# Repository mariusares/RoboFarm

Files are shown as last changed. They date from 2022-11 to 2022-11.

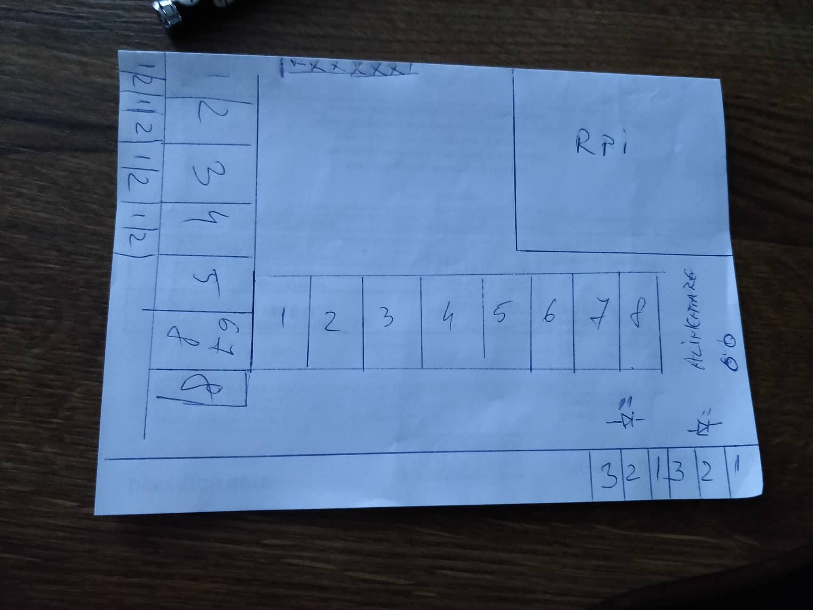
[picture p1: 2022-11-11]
CeresOne/Resources/board 1.jpg

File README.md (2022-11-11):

RoboFarm Greenhouse Automation, Irrigation Automation, and Poultry Farm Automation with Arduino and Raspberry Pi 

Long story short, a few years ago (in 2017 i think), a guy criticized the graphical interface.

At that moment I realized that he has to be a part of the team. 

So the GUI look and feel by Alex Hodorogea 

The PHP GUI (HTML folder) is in the Romanian language. Would be translated at some stage (too busy nowadays).

The sql file contains the MySQL/MariaDB SQL database structure

The default username is admin password admin 

For those who want more than a test, the PCB Layout is available for printing under CeresOne folder.

Initially, I gave up the name RoboFarm, because so many projects with this name. Feel free to name it as you pleased.

Under CeresOne/Resources you can see the pieces of the schematics, and how the power source and PCB board were designed. 

The project can work with a radio module with some software modifications.

Feel free to use it as you pleased. 

First version based on Arduino Mega with Google Docs logs  in production on 2015 :

https://www.youtube.com/watch?v=YMtiKbJgd4w&t=180s

First RaspberryPi + Arduino (Arduino is the sensor hub to feed the RPi data string) + first Web GUI:

https://www.youtube.com/watch?v=SSzuTgg7uxc&t=3s

png folder contains the new (actual) GUI version.

The system is designed to reduce farming costs and effort.

I hope that there would be a very happy farmer. 

The system was designed to help my uncle and every farmer that might need a bit of "help".

RoboFarm can be the best employee, he can ventilate the farm at 5AM if necessary.

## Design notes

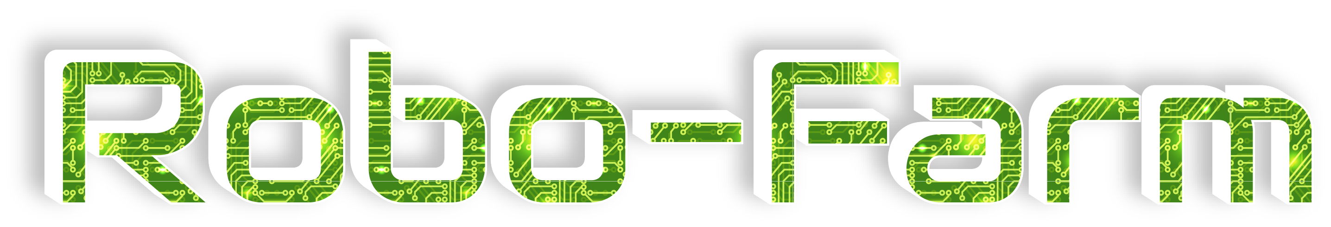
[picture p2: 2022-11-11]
html/img/robo-farm1.png

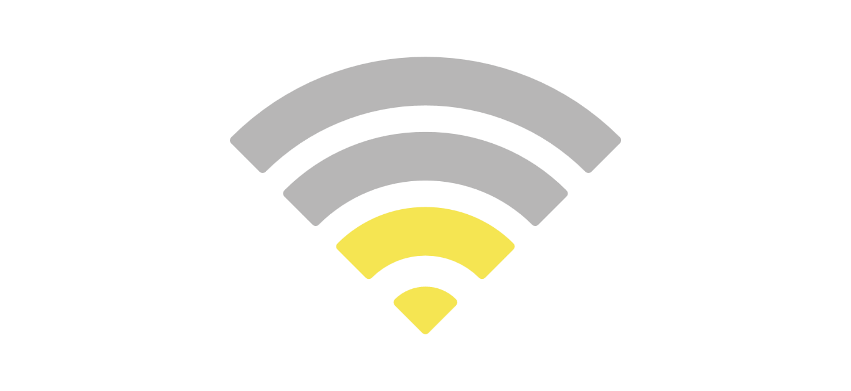
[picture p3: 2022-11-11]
html/img/2wq.png

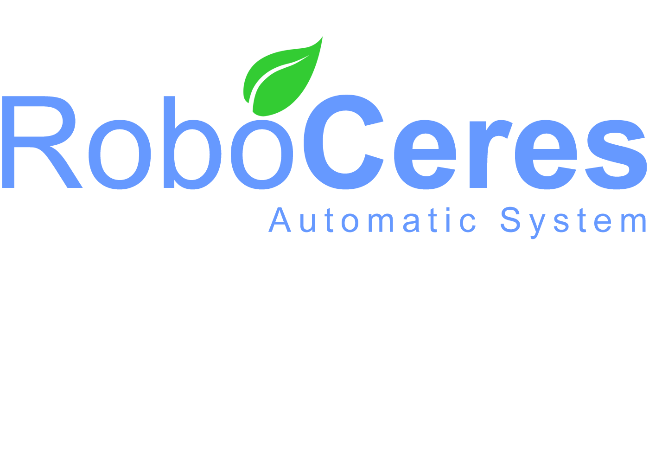
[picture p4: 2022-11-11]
html/img/RoboCeres.png

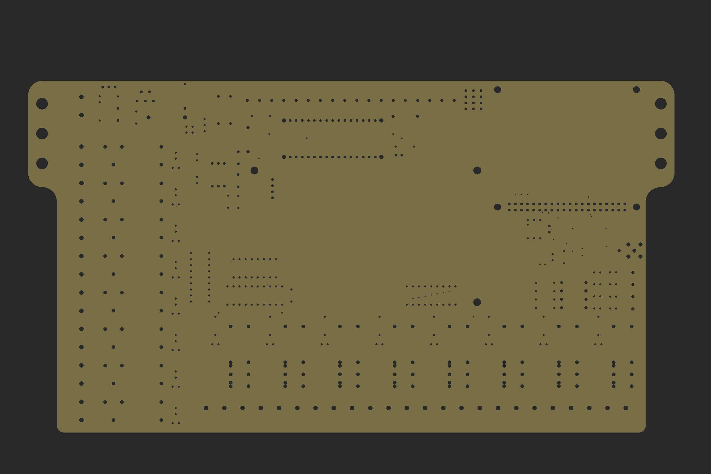
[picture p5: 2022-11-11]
CeresOne/Previews/Drill Map.png

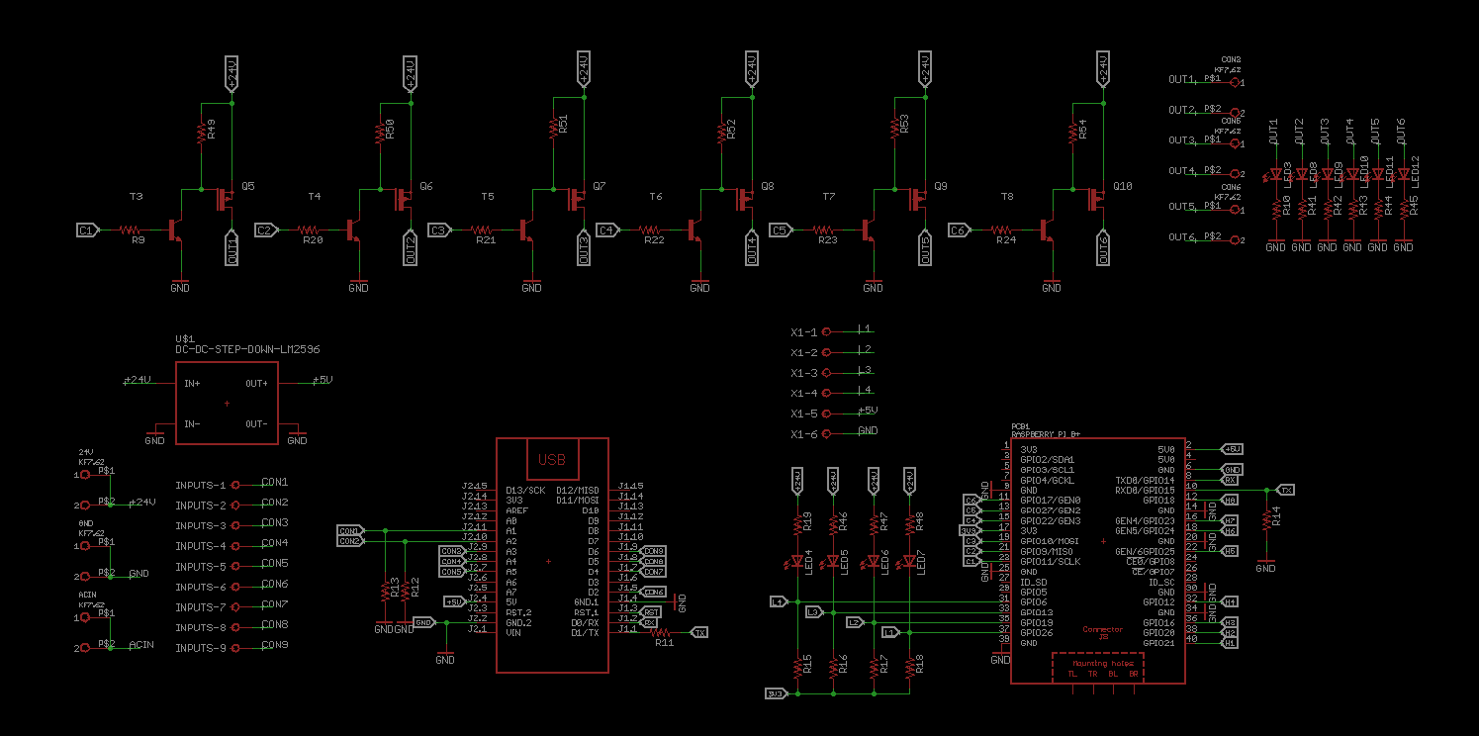
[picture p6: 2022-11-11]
CeresOne/Resources/Capture.PNG

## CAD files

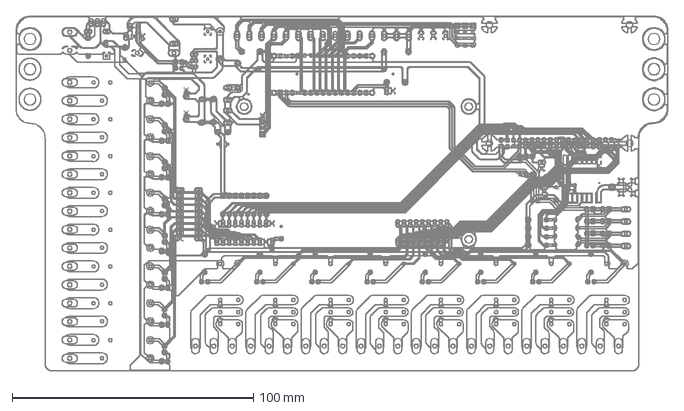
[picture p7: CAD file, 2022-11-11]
CeresOne/CAD/Board Outline.dxf
270.0 x 147.0 mm

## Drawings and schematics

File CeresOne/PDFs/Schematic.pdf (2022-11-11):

VIN J2.1 | GND.2 J2.2 | RST.2 J2.3 | 5V J2.4 | A7 J2.5 | A6 J2.6 | A5 J2.7 | A4 J2.8 | A3 J2.9 | A2 J2.10 | A1 J2.11 | A0 J2.12 | AREF J2.13 | 3V3 J2.14 | D13/SCK J2.15

## USB

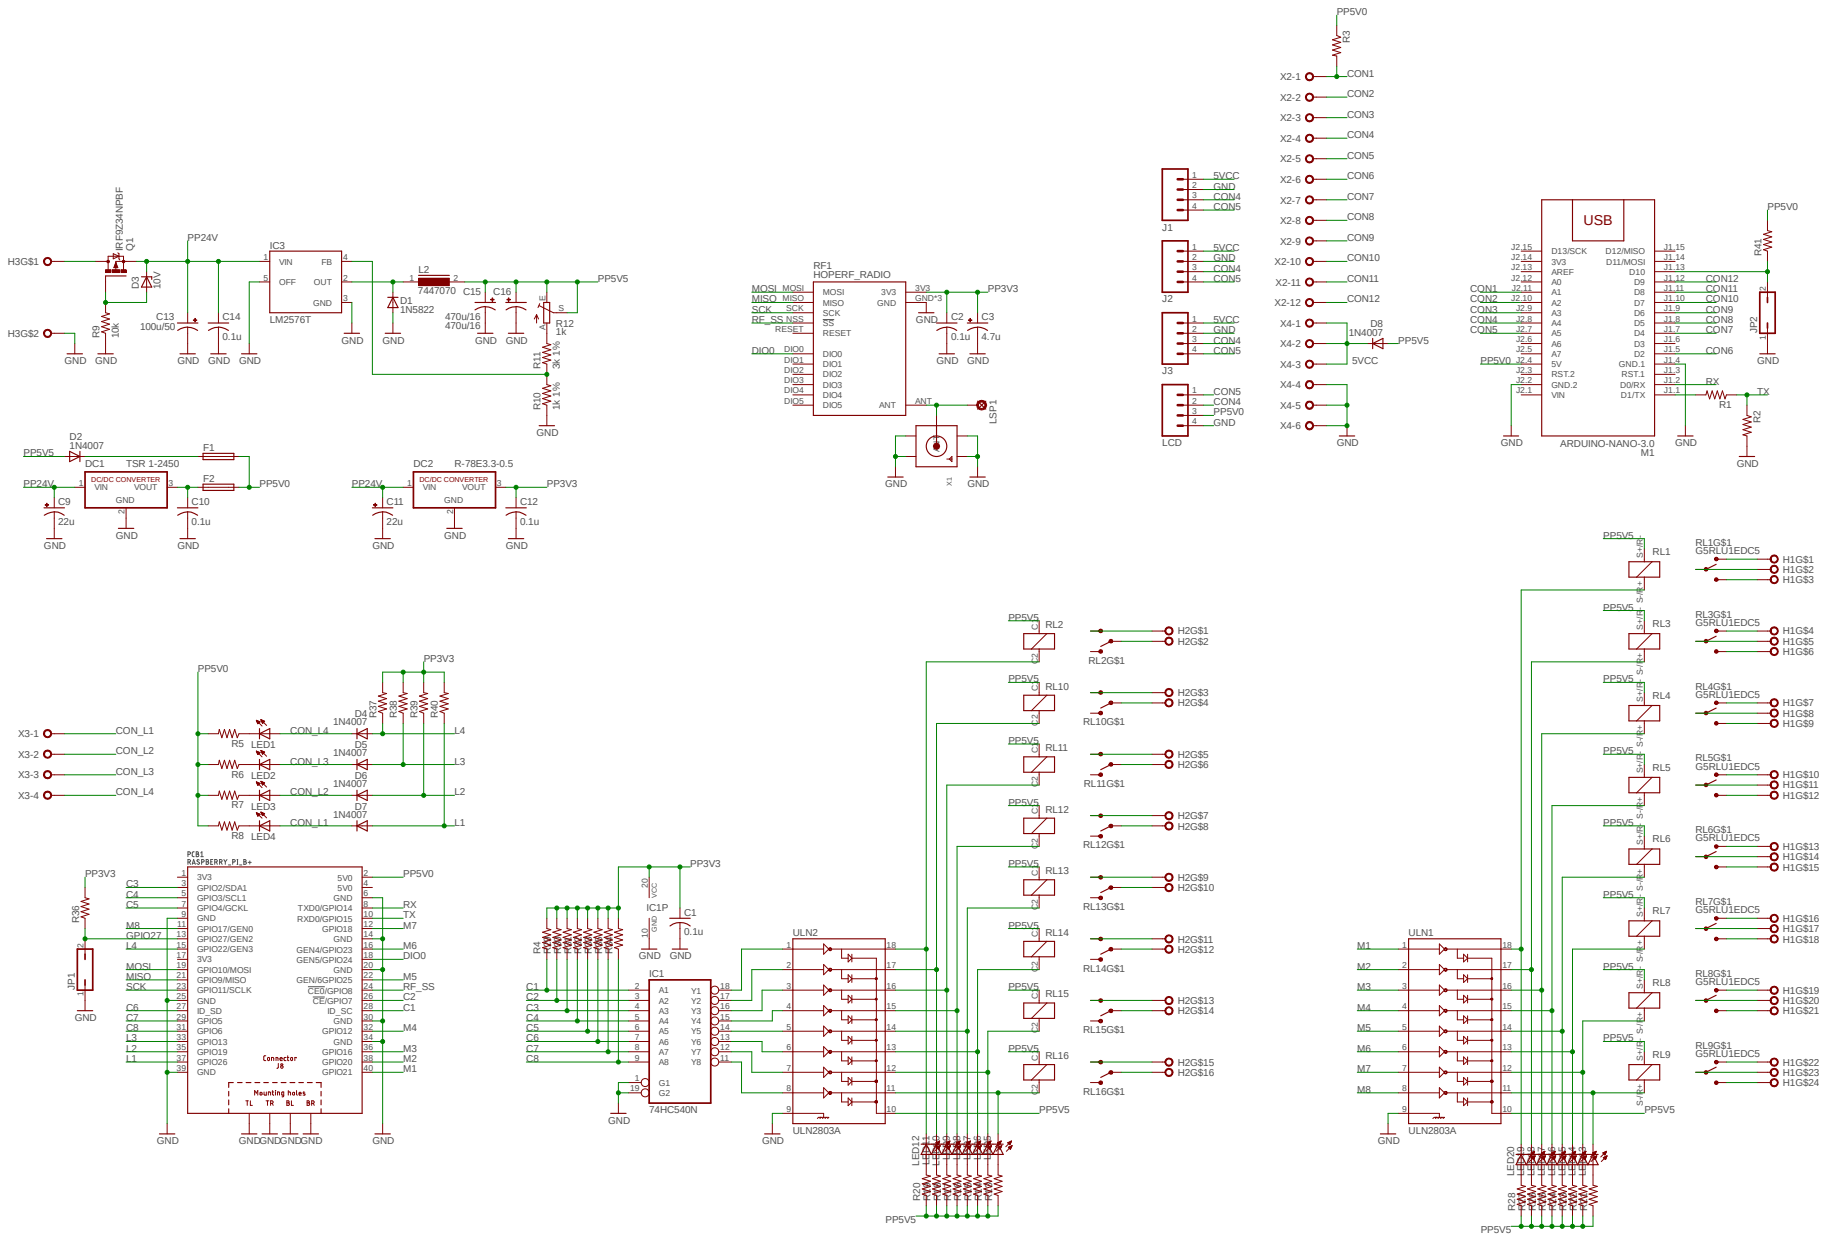
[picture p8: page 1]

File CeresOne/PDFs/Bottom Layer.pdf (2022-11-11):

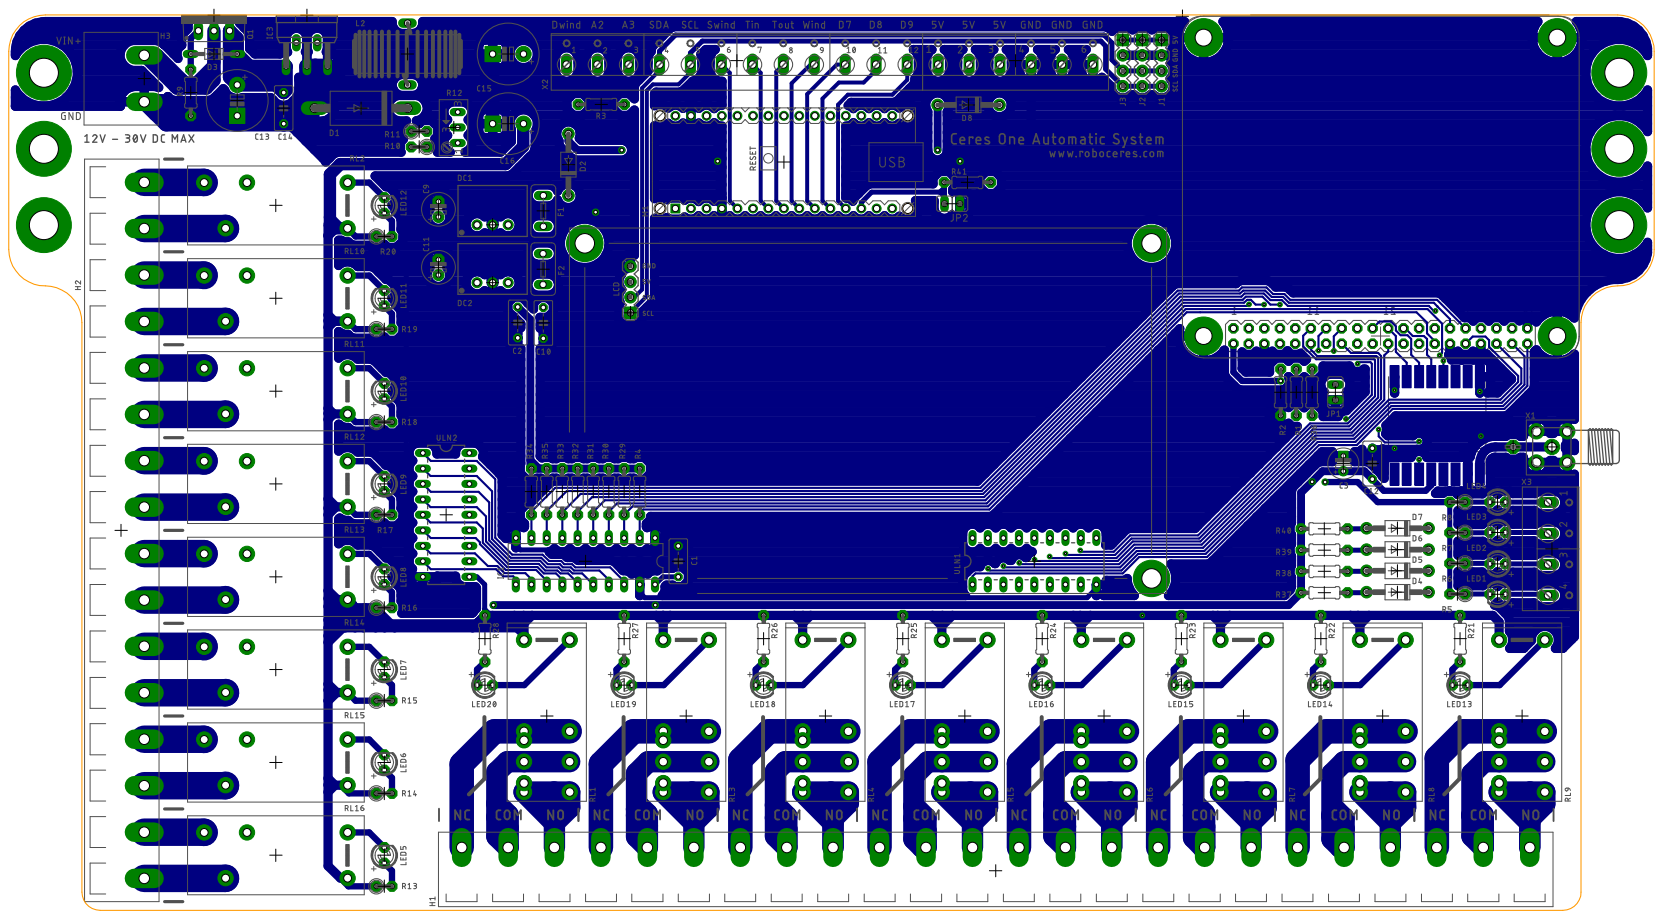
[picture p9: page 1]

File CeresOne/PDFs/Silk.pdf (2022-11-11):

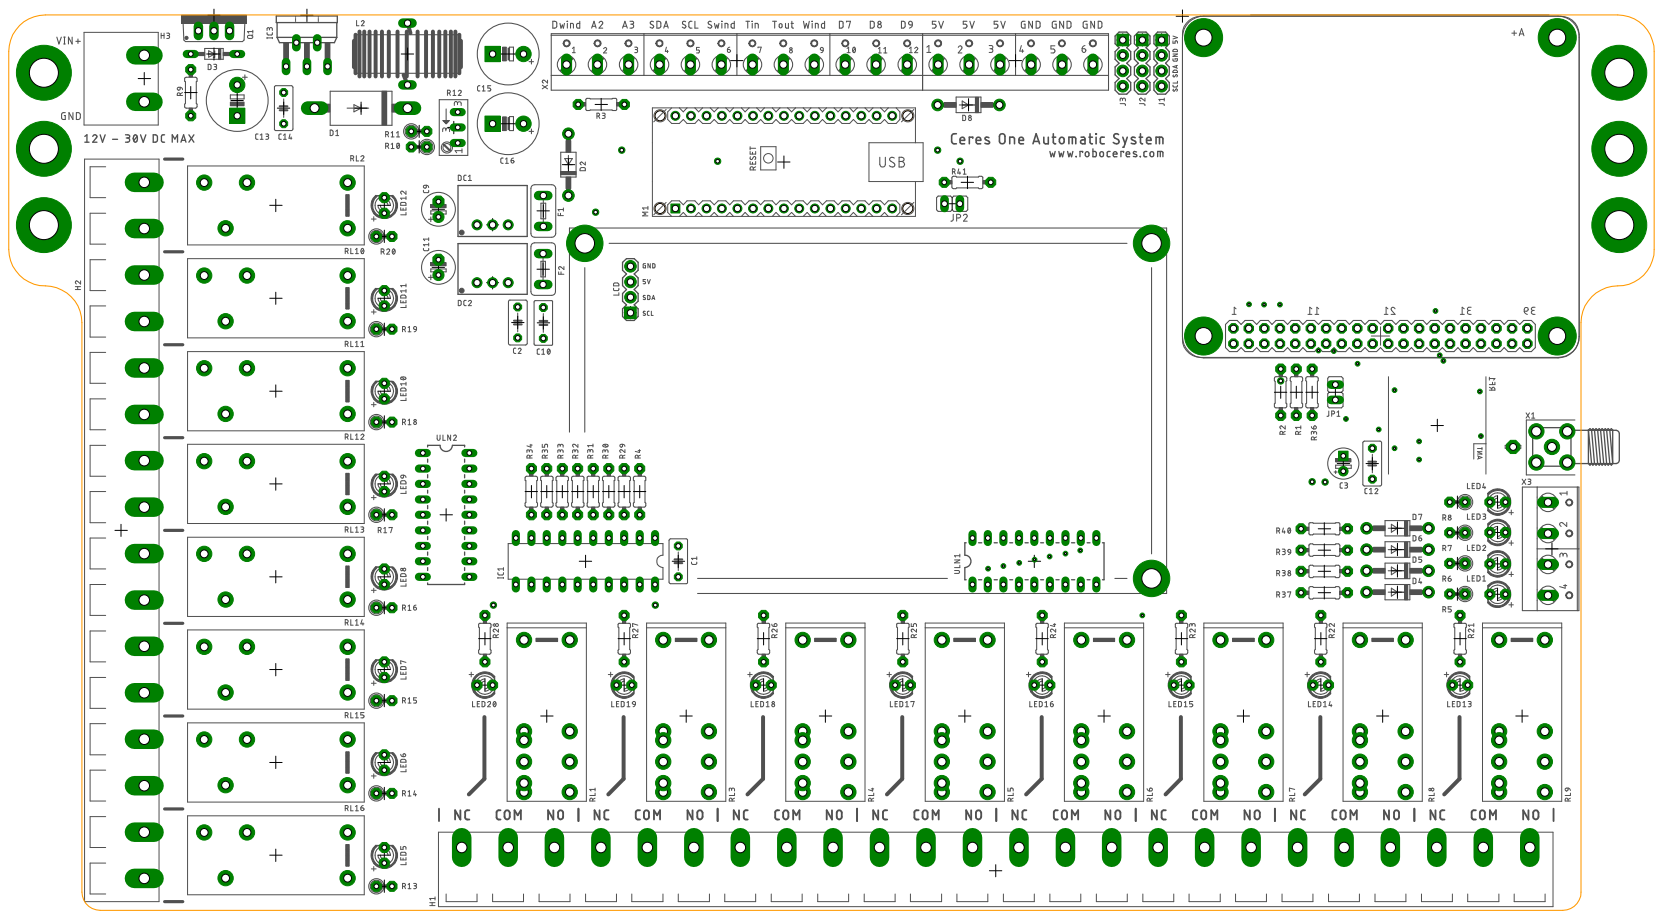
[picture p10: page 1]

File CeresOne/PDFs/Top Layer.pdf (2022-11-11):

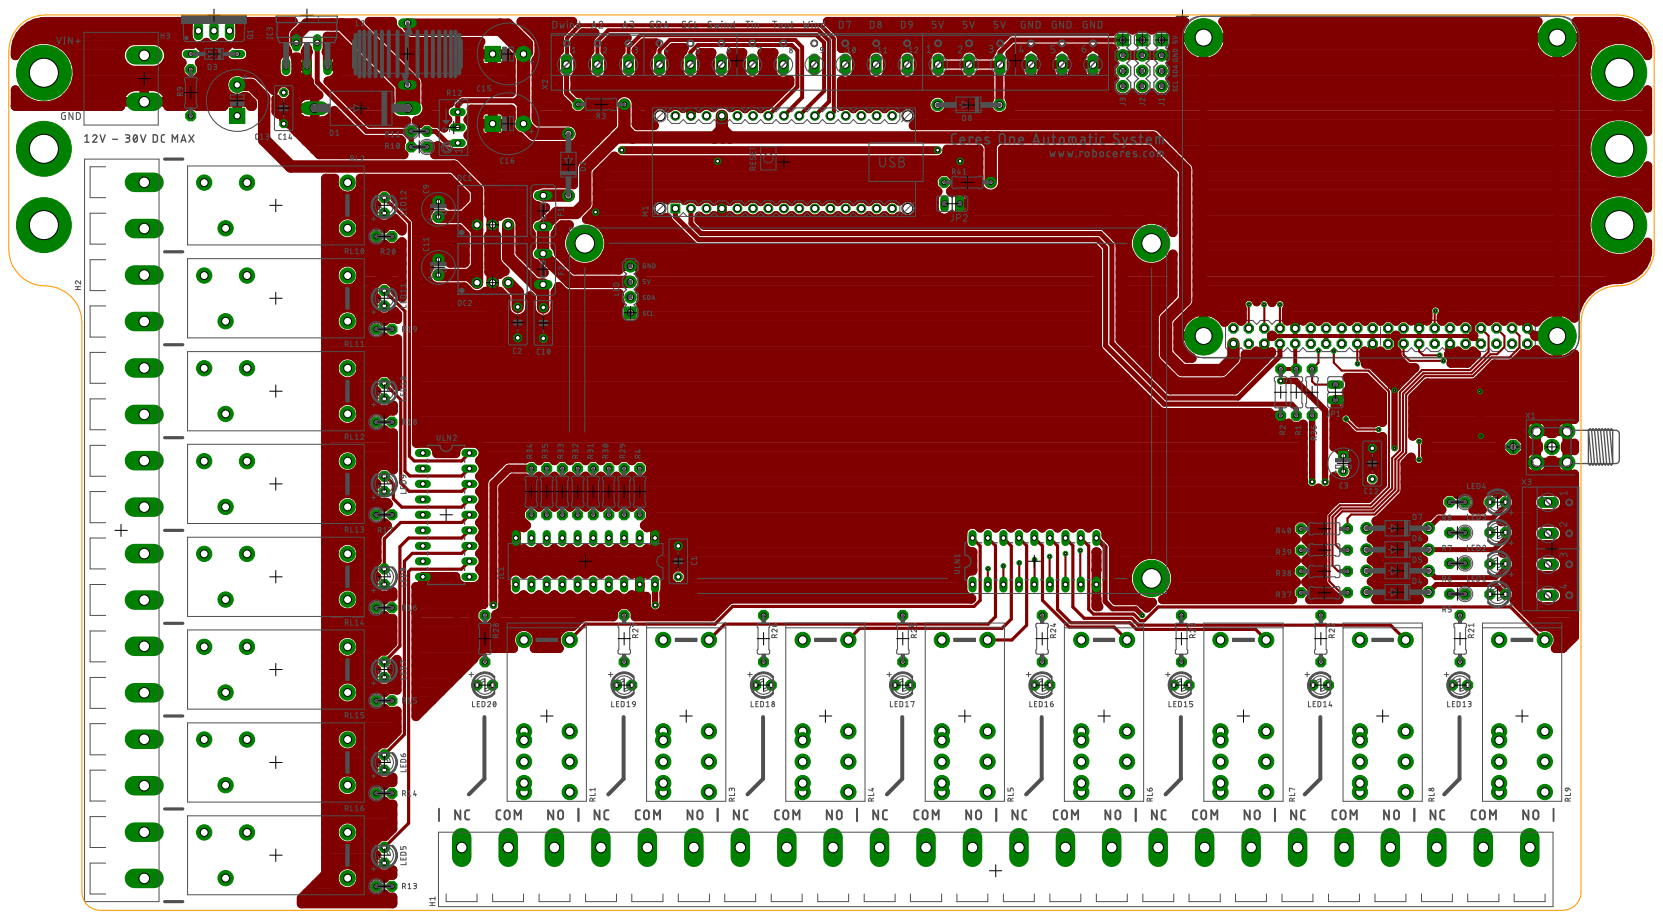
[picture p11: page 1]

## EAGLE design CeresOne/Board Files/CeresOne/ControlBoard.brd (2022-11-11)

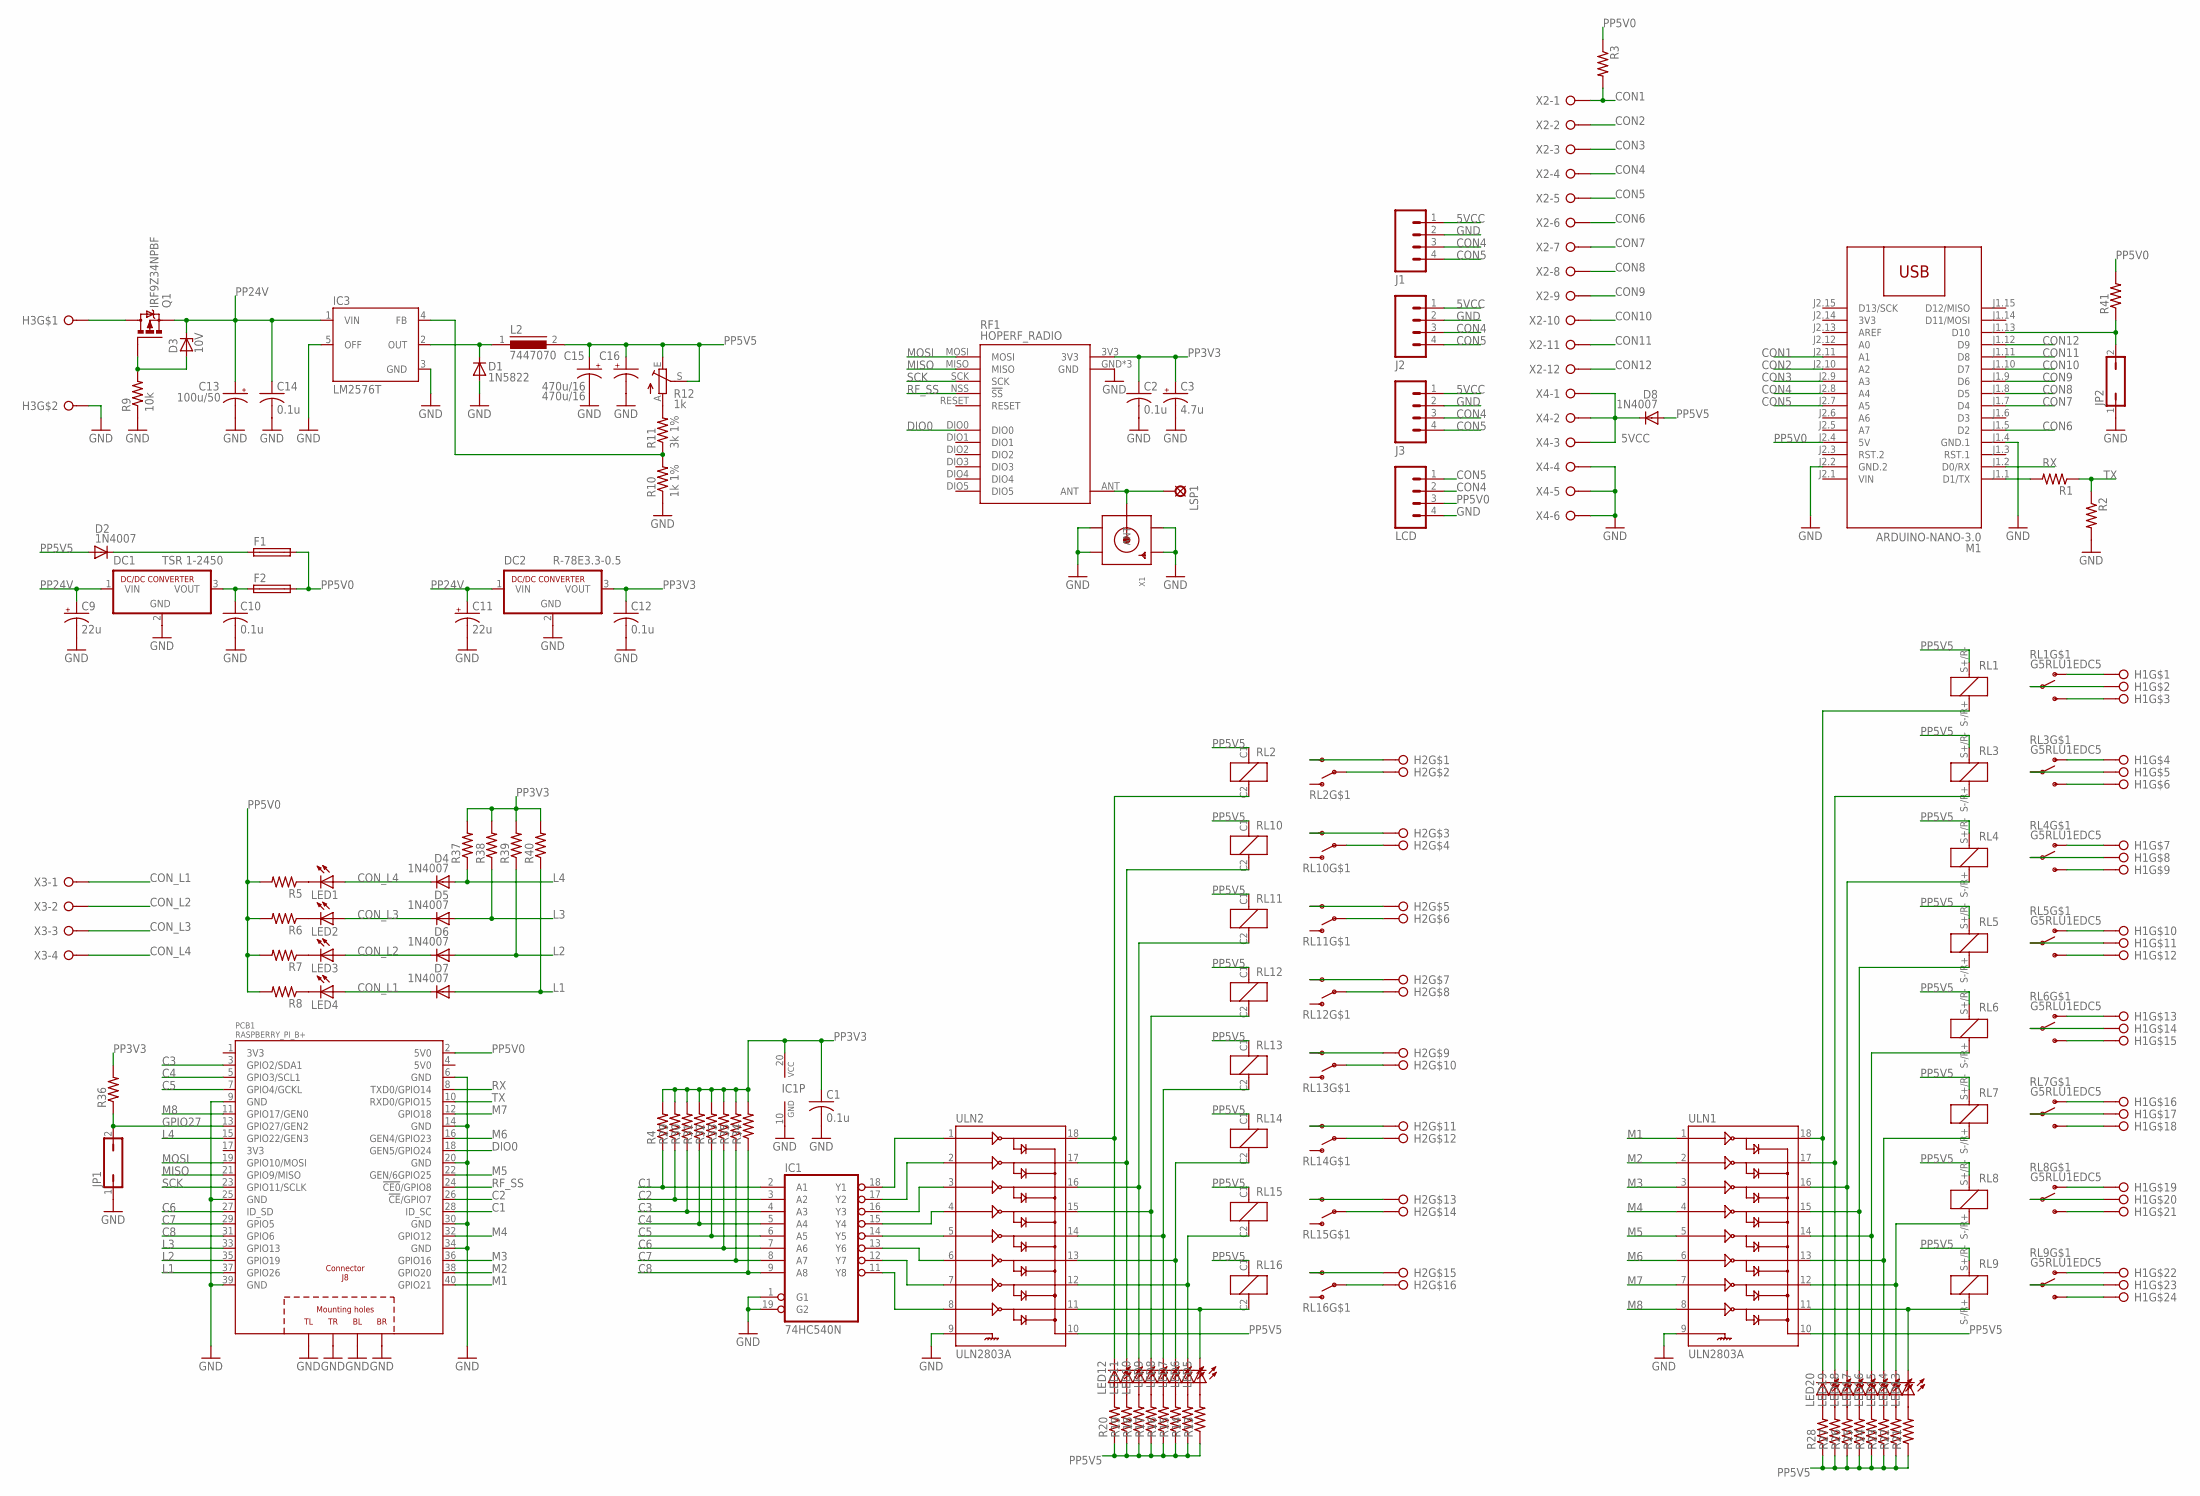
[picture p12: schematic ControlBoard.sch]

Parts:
C1, C2, C10, C12, C14: 0.1u; C050-030X075
C3: 4.7u; E2,5-5
C9, C11: 22u; E2,5-6
C13: 100u/50; E5-10,5
C15, C16: 470u/16; E5-10,5
D1: 1N5822; DO201-15
D2, D4, D5, D6, D7, D8: 1N4007; DO41-10
D3: 10V; DO34Z7
DC1: TSR 1-2450; SIP3
DC2: R-78E3.3-0.5; SIP3
F1, F2: TE5
H1: 24X1(0.300)CONN; 24/7.62CONN
H2: 16X1(0.300)CONN; 16/7.62CONN
H3: 2X1(0.300)CONN; 2/7.62CONN
IC1: 74HC540N; DIL20
IC3: LM2576T; TO220-5
J1, J2, J3: M04PTH; 1X04
JP1, JP2: JP1Q; JP1
L2: 7447070; SFT830D
LCD: M04PTH; 1X04
LED1, LED2, LED3, LED4, LED5, LED6, LED7, LED8, LED9, LED10, LED11, LED12, LED13, LED14, LED15, LED16, LED17, LED18, LED19, LED20: LED3MM
LSP1: LSP11
M1: ARDUINO-NANO-3.0
PCB1: RASPBERRY_PI_B+
Q1: IRF9Z34NPBF; TO220BV
R1, R2, R3, R4, R21, R22, R23, R24, R25, R26, R27, R28, R29, R30, R31, R32, R33, R34, R35, R36, R37, R38, R39, R40, R41: R-US_0204/7; 0204/7
R5, R6, R7, R8, R13, R14, R15, R16, R17, R18, R19, R20: R-US_0207/2V; 0207/2V
R9: 10k; 0204/7
R10: 1k 1%; 0207/2V
R11: 3k 1%; 0207/2V
R12: 1k; RJ9W
RF1: HOPERF_RADIO; RADIO_MODULE
RL1, RL3, RL4, RL5, RL6, RL7, RL8, RL9: G5RLU1EDC5; DOUBLE_RELAY
RL2, RL10, RL11, RL12, RL13, RL14, RL15, RL16: OMIH-SS-105LM,300
ULN1, ULN2: ULN2803A; DIL18
X1: SMACONNECTOR; SMA90_DIP
X2: W237-12P
X3: W237-04P; W237-4P
X4: W237-06P; W237-6P

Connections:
3V3: M1.J2.14 (3V3)
5VCC: D8.C, J1.1, J2.1, J3.1, X4.1, X4.2, X4.3
C1: IC1.2 (A1), PCB1.28 (ID_SC), R4.1
C2: IC1.3 (A2), PCB1.26 (!CE!/GPIO7), R29.1
C3: IC1.4 (A3), PCB1.3 (GPIO2/SDA1), R30.1
C4: IC1.5 (A4), PCB1.5 (GPIO3/SCL1), R31.1
C5: IC1.6 (A5), PCB1.7 (GPIO4/GCKL), R32.1
C6: IC1.7 (A6), PCB1.27 (ID_SD), R33.1
C7: IC1.8 (A7), PCB1.29 (GPIO5), R35.1
C8: IC1.9 (A8), PCB1.31 (GPIO6), R34.1
CON1: M1.J2.11 (A1), R3.2, X2.1
CON2: M1.J2.10 (A2), X2.2
CON3: M1.J2.9 (A3), X2.3
CON4: J1.3, J2.3, J3.3, LCD.2, M1.J2.8 (A4), X2.4
CON5: J1.4, J2.4, J3.4, LCD.1, M1.J2.7 (A5), X2.5
CON6: M1.J1.5 (D2), X2.6
CON7: M1.J1.7 (D4), X2.7
CON8: M1.J1.8 (D5), X2.8
CON9: M1.J1.9 (D6), X2.9
CON10: M1.J1.10 (D7), X2.10
CON11: M1.J1.11 (D8), X2.11
CON12: M1.J1.12 (D9), X2.12
CON_L1: D7.C, LED4.A, X3.1
CON_L2: D6.C, LED3.A, X3.2
CON_L3: D5.C, LED2.A, X3.3
CON_L4: D4.C, LED1.A, X3.4
DIO0: PCB1.18 (GEN5/GPIO24), RF1.DIO0
GND: C1.2, C2.2, C3.-, C9.-, C10.2, C11.-, C12.2, C13.-, C14.2, C15.-, C16.-, D1.A, DC1.2 (GND), DC2.2 (GND), H3.P$2, IC1.1 (G1), IC1.10 (GND), IC1.19 (G2), IC3.3 (GND), IC3.5 (OFF), J1.2, J2.2, J3.2, JP1.1, JP2.1, LCD.4, M1.J1.4 (GND.1), M1.J2.2 (GND.2), PCB1.6 (GND), PCB1.9 (GND), PCB1.14 (GND), PCB1.20 (GND), PCB1.25 (GND), PCB1.30 (GND), PCB1.34 (GND), PCB1.39 (GND), PCB1.PE_BL (BL), PCB1.PE_BR (BR), PCB1.PE_TL (TL), PCB1.PE_TR (TR), R2.2, R9.1, R10.1, RF1.GND, RF1.GND1 (GND), RF1.GND2 (GND), ULN1.9, ULN2.9, X1.GND1, X1.GND2, X1.GND3, X1.GND4, X4.4, X4.5, X4.6
GPIO27: JP1.2, PCB1.13 (GPIO27/GEN2), R36.1
L1: D7.A, PCB1.37 (GPIO26), R40.1
L2: D6.A, PCB1.35 (GPIO19), R39.1
L3: D5.A, PCB1.33 (GPIO13), R38.1
L4: D4.A, PCB1.15 (GPIO22/GEN3), R37.1
M1: PCB1.40 (GPIO21), ULN1.1
M2: PCB1.38 (GPIO20), ULN1.2
M3: PCB1.36 (GPIO16), ULN1.3
M4: PCB1.32 (GPIO12), ULN1.4
M5: PCB1.22 (GEN/6GPIO25), ULN1.5
M6: PCB1.16 (GEN4/GPIO23), ULN1.6
M7: PCB1.12 (GPIO18), ULN1.7
M8: PCB1.11 (GPIO17/GEN0), ULN1.8
MISO: PCB1.21 (GPIO9/MISO), RF1.MISO
MOSI: PCB1.19 (GPIO10/MOSI), RF1.MOSI
unnamed: H1.1, RL1.NC1 (NC), RL1.NC2 (NC), RL1.NC3 (NC)
unnamed: H1.3, RL1.NO1 (NO), RL1.NO2 (NO), RL1.NO3 (NO)
unnamed: H1.4, RL3.NC1 (NC), RL3.NC2 (NC), RL3.NC3 (NC)
unnamed: H1.6, RL3.NO1 (NO), RL3.NO2 (NO), RL3.NO3 (NO)
unnamed: H1.7, RL4.NC1 (NC), RL4.NC2 (NC), RL4.NC3 (NC)
unnamed: H1.9, RL4.NO1 (NO), RL4.NO2 (NO), RL4.NO3 (NO)
unnamed: H1.10, RL5.NC1 (NC), RL5.NC2 (NC), RL5.NC3 (NC)
unnamed: H1.12, RL5.NO1 (NO), RL5.NO2 (NO), RL5.NO3 (NO)
unnamed: H1.13, RL6.NC1 (NC), RL6.NC2 (NC), RL6.NC3 (NC)
unnamed: H1.15, RL6.NO1 (NO), RL6.NO2 (NO), RL6.NO3 (NO)
unnamed: H1.16, RL7.NC1 (NC), RL7.NC2 (NC), RL7.NC3 (NC)
unnamed: H1.18, RL7.NO1 (NO), RL7.NO2 (NO), RL7.NO3 (NO)
unnamed: H1.19, RL8.NC1 (NC), RL8.NC2 (NC), RL8.NC3 (NC)
unnamed: H1.21, RL8.NO1 (NO), RL8.NO2 (NO), RL8.NO3 (NO)
unnamed: H1.22, RL9.NC1 (NC), RL9.NC2 (NC), RL9.NC3 (NC)
unnamed: H1.24, RL9.NO1 (NO), RL9.NO2 (NO), RL9.NO3 (NO)
unnamed: H1.2, RL1.COM1 (COM), RL1.COM2 (COM)
unnamed: H1.5, RL3.COM1 (COM), RL3.COM2 (COM)
unnamed: H1.8, RL4.COM1 (COM), RL4.COM2 (COM)
unnamed: H1.11, RL5.COM1 (COM), RL5.COM2 (COM)
unnamed: H1.14, RL6.COM1 (COM), RL6.COM2 (COM)
unnamed: H1.17, RL7.COM1 (COM), RL7.COM2 (COM)
unnamed: H1.20, RL8.COM1 (COM), RL8.COM2 (COM)
unnamed: H1.23, RL9.COM1 (COM), RL9.COM2 (COM)
unnamed: H2.2, RL2.COM
unnamed: H2.4, RL10.COM
unnamed: H2.6, RL11.COM
unnamed: H2.8, RL12.COM
unnamed: H2.10, RL13.COM
unnamed: H2.12, RL14.COM
unnamed: H2.14, RL15.COM
unnamed: H2.16, RL16.COM
unnamed: H2.1, RL2.NO
unnamed: H2.3, RL10.NO
unnamed: H2.5, RL11.NO
unnamed: H2.7, RL12.NO
unnamed: H2.9, RL13.NO
unnamed: H2.11, RL14.NO
unnamed: H2.13, RL15.NO
unnamed: H2.15, RL16.NO
unnamed: LED13.K (C), RL9.S-/R+ (2), ULN1.11
unnamed: LED14.K (C), RL8.S-/R+ (2), ULN1.12
unnamed: LED15.K (C), RL7.S-/R+ (2), ULN1.13
unnamed: LED16.K (C), RL6.S-/R+ (2), ULN1.14
unnamed: LED17.K (C), RL5.S-/R+ (2), ULN1.15
unnamed: LED18.K (C), RL4.S-/R+ (2), ULN1.16
unnamed: LED19.K (C), RL3.S-/R+ (2), ULN1.17
unnamed: LED20.K (C), RL1.S-/R+ (2), ULN1.18
unnamed: LED12.K (C), RL2.C2 (2), ULN2.18
unnamed: LED11.K (C), RL10.C2 (2), ULN2.17
unnamed: LED10.K (C), RL11.C2 (2), ULN2.16
unnamed: LED9.K (C), RL12.C2 (2), ULN2.15
unnamed: LED8.K (C), RL13.C2 (2), ULN2.14
unnamed: LED7.K (C), RL14.C2 (2), ULN2.13
unnamed: LED6.K (C), RL15.C2 (2), ULN2.12
unnamed: LED5.K (C), RL16.C2 (2), ULN2.11
unnamed: IC1.11 (Y8), ULN2.8
unnamed: IC1.12 (Y7), ULN2.7
unnamed: IC1.13 (Y6), ULN2.6
unnamed: IC1.14 (Y5), ULN2.5
unnamed: IC1.15 (Y4), ULN2.4
unnamed: IC1.16 (Y3), ULN2.3
unnamed: IC1.17 (Y2), ULN2.2
unnamed: IC1.18 (Y1), ULN2.1
unnamed: LSP1.MP, RF1.ANT, X1.ANTENNA (ANT)
unnamed: M1.J1.1 (D1/TX), R1.2
unnamed: LED1.K (C), R5.1
unnamed: LED2.K (C), R6.1
unnamed: LED3.K (C), R7.1
unnamed: D3.A, Q1.G, R9.2
unnamed: IC3.4 (FB), R10.2, R11.1
unnamed: LED4.K (C), R8.1
unnamed: H3.P$1, Q1.D
unnamed: D2.C, F1.1
unnamed: C10.1, DC1.3 (VOUT), F2.1
unnamed: D1.C, IC3.2 (OUT), L2.1
unnamed: R11.2, R12.A
unnamed: LED5.A, R13.2
unnamed: LED6.A, R14.2
unnamed: LED7.A, R15.2
unnamed: LED8.A, R16.2
unnamed: LED9.A, R17.2
unnamed: LED10.A, R18.2
unnamed: LED11.A, R19.2
unnamed: LED12.A, R20.2
unnamed: LED13.A, R21.2
unnamed: LED14.A, R22.2
unnamed: LED15.A, R23.2
unnamed: LED16.A, R24.2
unnamed: LED17.A, R25.2
unnamed: LED18.A, R26.2
unnamed: LED19.A, R27.2
unnamed: LED20.A, R28.2
unnamed: JP2.2, M1.J1.13 (D10), R41.1
PP3V3: C1.1, C2.1, C3.+, C12.1, DC2.3 (VOUT), IC1.20 (VCC), R4.2, R29.2, R30.2, R31.2, R32.2, R33.2, R34.2, R35.2, R36.2, R37.2, R38.2, R39.2, R40.2, RF1.3V3
PP5V0: F1.2, F2.2, LCD.3, M1.J2.4 (5V), PCB1.2 (5V0), R3.1, R5.2, R6.2, R7.2, R8.2, R41.2
PP5V5: C15.+, C16.+, D2.A, D8.A, L2.2, R12.E, R12.S, R13.1, R14.1, R15.1, R16.1, R17.1, R18.1, R19.1, R20.1, R21.1, R22.1, R23.1, R24.1, R25.1, R26.1, R27.1, R28.1, RL1.S+/R- (1), RL2.C1 (1), RL3.S+/R- (1), RL4.S+/R- (1), RL5.S+/R- (1), RL6.S+/R- (1), RL7.S+/R- (1), RL8.S+/R- (1), RL9.S+/R- (1), RL10.C1 (1), RL11.C1 (1), RL12.C1 (1), RL13.C1 (1), RL14.C1 (1), RL15.C1 (1), RL16.C1 (1), ULN1.10, ULN2.10
PP24V: C9.+, C11.+, C13.+, C14.1, D3.C, DC1.1 (VIN), DC2.1 (VIN), IC3.1 (VIN), Q1.S
RF_SS: PCB1.24 (!CE0!/GPIO8), RF1.NSS (!SS)
RX: M1.J1.2 (D0/RX), PCB1.8 (TXD0/GPIO14)
SCK: PCB1.23 (GPIO11/SCLK), RF1.SCK
TX: PCB1.10 (RXD0/GPIO15), R1.1, R2.1
VIN: M1.J2.1 (VIN)

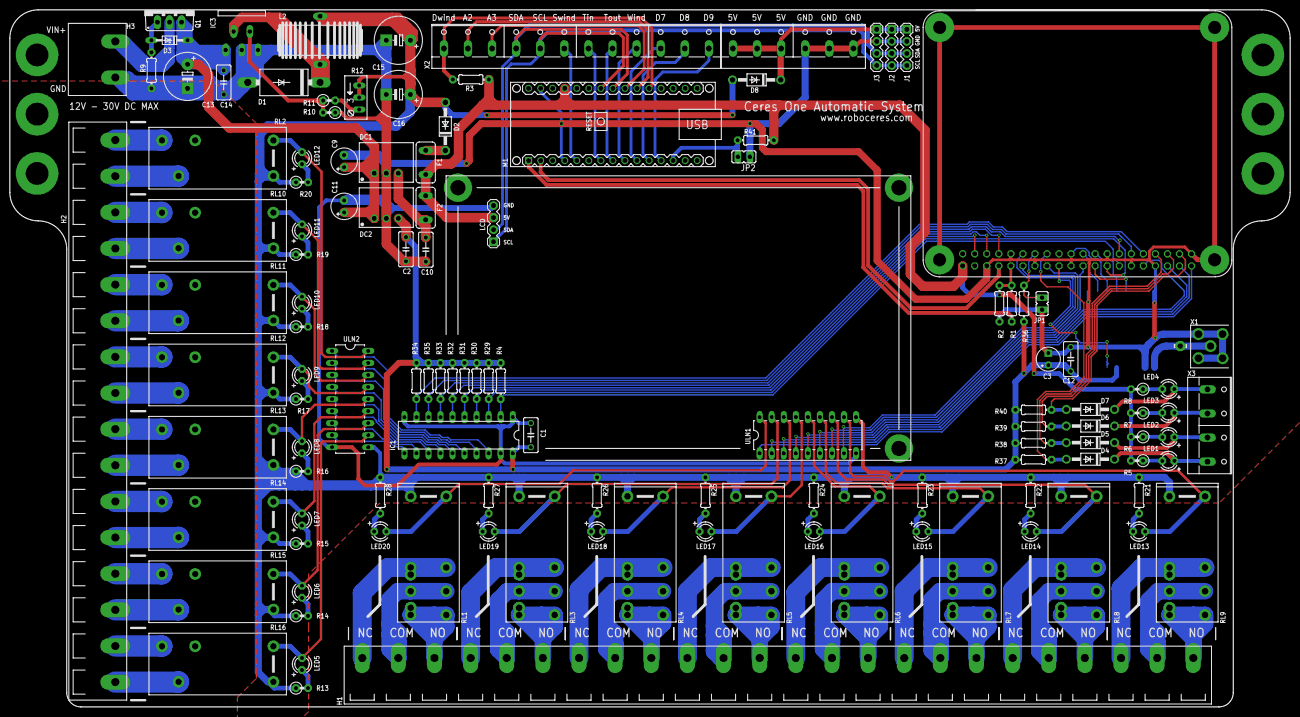
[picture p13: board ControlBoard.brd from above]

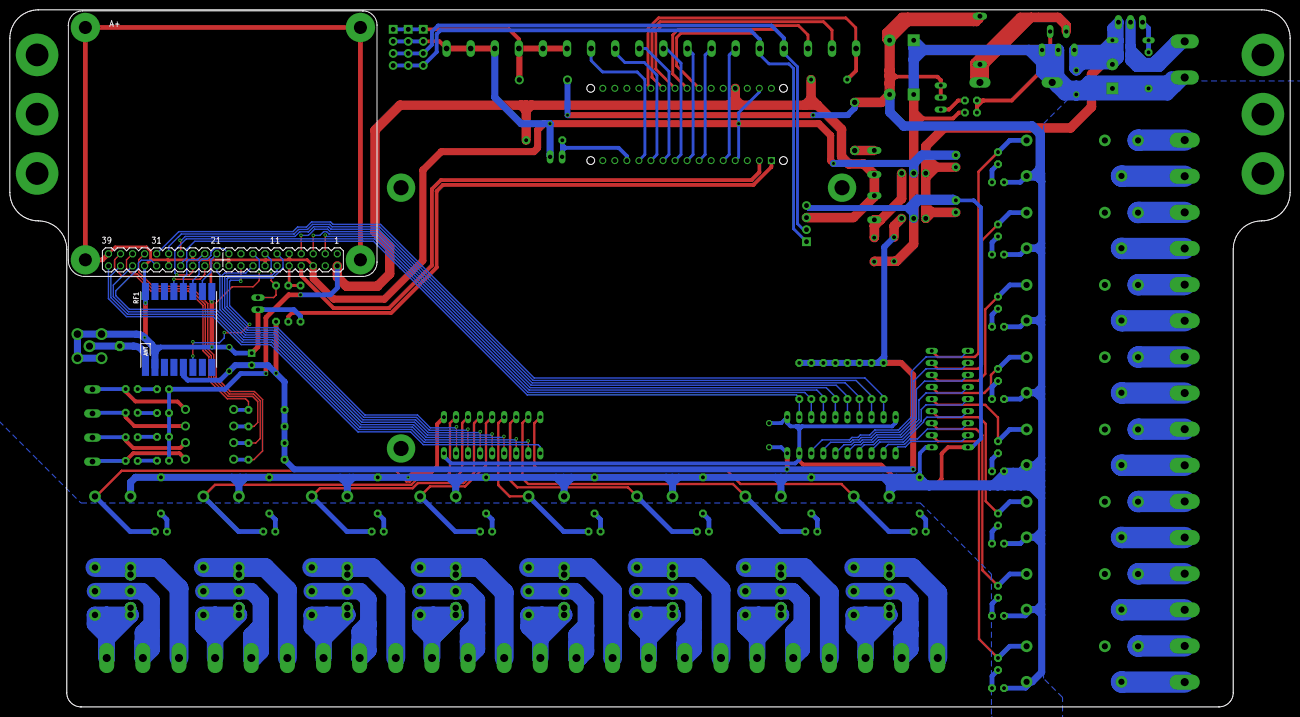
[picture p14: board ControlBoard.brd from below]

Board: 2 copper layers, 270.0 x 147.0 mm, 123 parts (2 on the bottom side), 144 nets.

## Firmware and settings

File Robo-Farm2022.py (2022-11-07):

#!/usr/bin/python3
import threading
import socketserver
import sys
import os
import signal
import serial
import time
import subprocess
import MySQLdb
import RPi.GPIO as GPIO
GPIO.setmode(GPIO.BCM)
from datetime import date



#Irrigation zone 1
flagZ1 = 0
flagZ1o = 0
activi1Z1 = 0
orai1 = 0
minuti1 = 0
orai1oprit = 0
minuti1oprit = 0
activh1Z1 = 0
orah1 = 0
minuth1 = 0
orah1oprit = 0
minuth1oprit = 0
activi2Z1 = 0
orai1t2 = 0
minuti1t2 = 0
orai1t2oprit = 0
minuti1t2oprit = 0
activh2Z1 = 0
orah1t2 = 0
minuth1t2 = 0
orah1t2oprit = 0
minuth1t2oprit = 0

#Irrigation Zone 2
flagZ2 = 0
flagZ2o = 0
activi1Z2 = 0
orai2 = 0
minuti2 = 0
orai2oprit = 0
minuti2oprit = 0
activh1Z2 = 0
orah2 = 0
minuth2 = 0
orah2oprit = 0
minuth2oprit = 0
activi2Z2 = 0
orai2t2 = 0
minuti2t2 = 0
orai2t2oprit = 0
minuti2t2oprit = 0
activh2Z2 = 0
orah2t2 = 0
minuth2t2 = 0
orah2t2oprit = 0
minuth2t2oprit = 0

#Irrigation Zone 3
flagZ3 = 0
flagZ3o = 0
activi1Z3 = 0
orai3 = 0
minuti3 = 0
orai3oprit = 0
minuti3oprit = 0
activh1Z3 = 0
orah3 = 0
minuth3 = 0
orah3oprit = 0
minuth3oprit = 0
activi2Z3 = 0
orai3t2 = 0
minuti3t2 = 0
orai3t2oprit = 0
minuti3t2oprit = 0
activh2Z3 = 0
orah3t2 = 0
minuth3t2 = 0
orah3t2oprit = 0
minuth3t2oprit = 0

#Irrigation Zone 4
flagZ4 = 0
flagZ4o = 0
activi1Z4 = 0
orai4 = 0
minuti4 = 0
orai4oprit = 0
minuti4oprit = 0
activh1Z4 = 0
orah4 = 0
minuth4 = 0
orah4oprit = 0
minuth4oprit = 0
activi2Z4 = 0
orai4t2 = 0
minuti4t2 = 0
orai4t2oprit = 0
minuti4t2oprit = 0
activh2Z4 = 0
orah4t2 = 0
minuth4t2 = 0
orah4t2oprit = 0
minuth4t2oprit = 0

#Irrigation Zone 5
flagZ5 = 0
flagZ5o = 0
activi1Z5 = 0
orai5 = 0
minuti5 = 0
orai5oprit = 0
minuti5oprit = 0
activh1Z5 = 0
orah5 = 0
minuth5 = 0
orah5oprit = 0
minuth5oprit = 0
activi2Z5 = 0
orai5t2 = 0
minuti5t2 = 0
orai5t2oprit = 0
minuti5t2oprit = 0
activh2Z5 = 0
orah5t2 = 0
minuth5t2 = 0
orah5t2oprit = 0
minuth5t2oprit = 0

#Irrigation Zone 6
flagZ6 = 0
flagZ6o = 0
activi1Z6 = 0
orai6 = 0
minuti6 = 0
orai6oprit = 0
minuti6oprit = 0
activh1Z6 = 0
orah6 = 0
minuth6 = 0
orah6oprit = 0
minuth6oprit = 0
activi2Z6 = 0
orai6t2 = 0
minuti6t2 = 0
orai6t2oprit = 0
minuti6t2oprit = 0
activh2Z6 = 0
orah6t2 = 0
minuth6t2 = 0
orah6t2oprit = 0
minuth6t2oprit = 0

#Auxiliary system settings with 6 or 2 irrigation zone
auxSet = 0
#auxiliare
enablevent = 0
startVent = 0
stopVent = 0
enableheat = 0
startHeat = 1
stopHeat = 2
enabledaynight = 0
dayTemp = 1
nightTemp = 1
dayLux = 200
nightLux = 0
tempLucru = 0
enablelight = 0
startLight = 0
stopLight = 0
enablehumi = 0
startHumi = 0
stopHumi = 0

#Time settings -hour minute second and day
ora = 0
minut = 0
secunda = 0
ziua = 0

###Arduino sensors data settings
viteza=0
rafala=0
directie=0
tIn=0
uIn=0
tOut=0
uOut=0
tAer=0
tSol=0
lumina=0
dataPHP=0
Terr=0


# MySQL CONFORT Settings


#Motor 1 settings
pozitionare1 = 0
activ1 = 0
Topen1 = 0
Tclose1 = 0
Wwind1 = 0
Wclose1 = 0
timecycle1 = 0
steps1 = 0
break1 = 0
treapta1 = 10
tpornit1 = 0
tnext1 = 0
toprit1 = 0


#Motor 2
pozitionare2 = 0
activ2 = 0
Topen2 = 0
Tclose2 = 0
Wwind2 = 0
Wclose2 = 0
timecycle2 = 0
steps2 = 0
break2 = 0
treapta2 = 10
tpornit2 = 0
tnext2 = 0
toprit2 = 0

#Motor 3  
pozitionare3 = 0
activ3 = 0
Topen3 = 0
Tclose3 = 0
Wwind3 = 0
Wclose3 = 0
timecycle3 = 0
steps3 = 0
break3 = 0
treapta3 = 10
tpornit3 = 0
tnext3 = 0
toprit3 = 0

#Motor 4 
pozitionare4 = 0
activ4 = 0
Topen4 = 0
Tclose4 = 0
Wwind4 = 0
Wclose4 = 0
timecycle4 = 0
steps4 = 0
break4 = 0
treapta4 = 10
tpornit4 = 0
tnext4 = 0
toprit4 = 0
treapta4 = 10
tpornit4 = 0
tnext4 = 0
toprit4 = 0


#RPi Digital Pins Allocation with full auxiliary and only 2 irrigation zones
pompaI = 1         #Irrigation Pump
pinH = 7           #Fertilizer pump
pinZ1 = 2          #Valve pin for zone 1
pinZ2 = 3          #valve pin for zone 2
fan = 4            #electric ventilation fan 
heat = 0           #heat system control
plumina = 5        #lighing system pin
pdehumi = 6        #dehumidifier pin

#RPi Digital Pins Allocation without auxiliary but 6 irrigation zones
pompaI = 1         #Irrigation Pump
pinH = 7           #Fertilizer pump
pinZ1 = 2          #Valve pin for zone 1
pinZ2 = 3          #Valve pin for zone 2
pinZ3 = 4          #Valve pin for zone 3
pinZ4 = 0          #Valve pin for zone 4
pinZ5 = 5          #Valve pin for zone 5
pinZ6 = 6          #Valve pin for zone 6


#RPi Digital pins allocation for Confort Module Ventilation Motors
DS = 21 
IS = 20 
DD = 16
ID = 12
DS2 = 25 
IS2 = 23 
DD2 = 18
ID2 = 17

#RPi Digital pins allocation for Limit Sensors
LS = 26
LD = 19
LS2 = 13
LD2 = 22
Rst = 27
Rerr = 0
GPIO.setup(Rst, GPIO.OUT)
GPIO.output(Rst, GPIO.HIGH)

GPIO.setup(pinZ1, GPIO.OUT)
GPIO.setup(pinZ2, GPIO.OUT)
GPIO.setup(pinH, GPIO.OUT)
GPIO.setup(pompaI, GPIO.OUT)
GPIO.setup(heat, GPIO.OUT)
GPIO.setup(fan, GPIO.OUT)
GPIO.setup(plumina, GPIO.OUT)
GPIO.setup(pdehumi, GPIO.OUT)
GPIO.output(pinZ1, GPIO.HIGH)
GPIO.output(pinZ2, GPIO.HIGH)
GPIO.output(pinH, GPIO.HIGH)
GPIO.output(pompaI, GPIO.HIGH)
GPIO.output(heat, GPIO.HIGH)
GPIO.output(fan, GPIO.HIGH)
GPIO.output(plumina, GPIO.HIGH)
GPIO.output(pdehumi, GPIO.HIGH)

GPIO.setup(DD, GPIO.OUT)
GPIO.output(DD, GPIO.LOW)
GPIO.setup(ID, GPIO.OUT)
GPIO.output(ID, GPIO.LOW)
GPIO.setup(DS, GPIO.OUT)
GPIO.output(DS, GPIO.LOW)
GPIO.setup(IS, GPIO.OUT)
GPIO.output(IS, GPIO.LOW)
GPIO.setup(DD2, GPIO.OUT)
GPIO.output(DD2, GPIO.LOW)
GPIO.setup(ID2, GPIO.OUT)
GPIO.output(ID2, GPIO.LOW)
GPIO.setup(DS2, GPIO.OUT)
GPIO.output(DS2, GPIO.LOW)
GPIO.setup(IS2, GPIO.OUT)
GPIO.output(IS2, GPIO.LOW)

GPIO.setup(LS, GPIO.IN, pull_up_down = GPIO.PUD_UP)
GPIO.setup(LD, GPIO.IN, pull_up_down = GPIO.PUD_UP)
GPIO.setup(LS2, GPIO.IN, pull_up_down = GPIO.PUD_UP)
GPIO.setup(LD2, GPIO.IN, pull_up_down = GPIO.PUD_UP)



def updateTime():
    global ora
    global minut
    ora = int(time.strftime("%H"))
    minut = int(time.strftime("%M"))
    secunda = int(time.strftime("%S"))
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

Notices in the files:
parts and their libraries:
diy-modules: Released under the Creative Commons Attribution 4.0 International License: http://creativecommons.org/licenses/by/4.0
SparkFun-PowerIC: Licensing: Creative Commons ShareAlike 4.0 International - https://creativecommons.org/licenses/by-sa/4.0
